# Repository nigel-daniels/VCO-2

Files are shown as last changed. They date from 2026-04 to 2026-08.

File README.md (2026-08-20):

# VCO 2

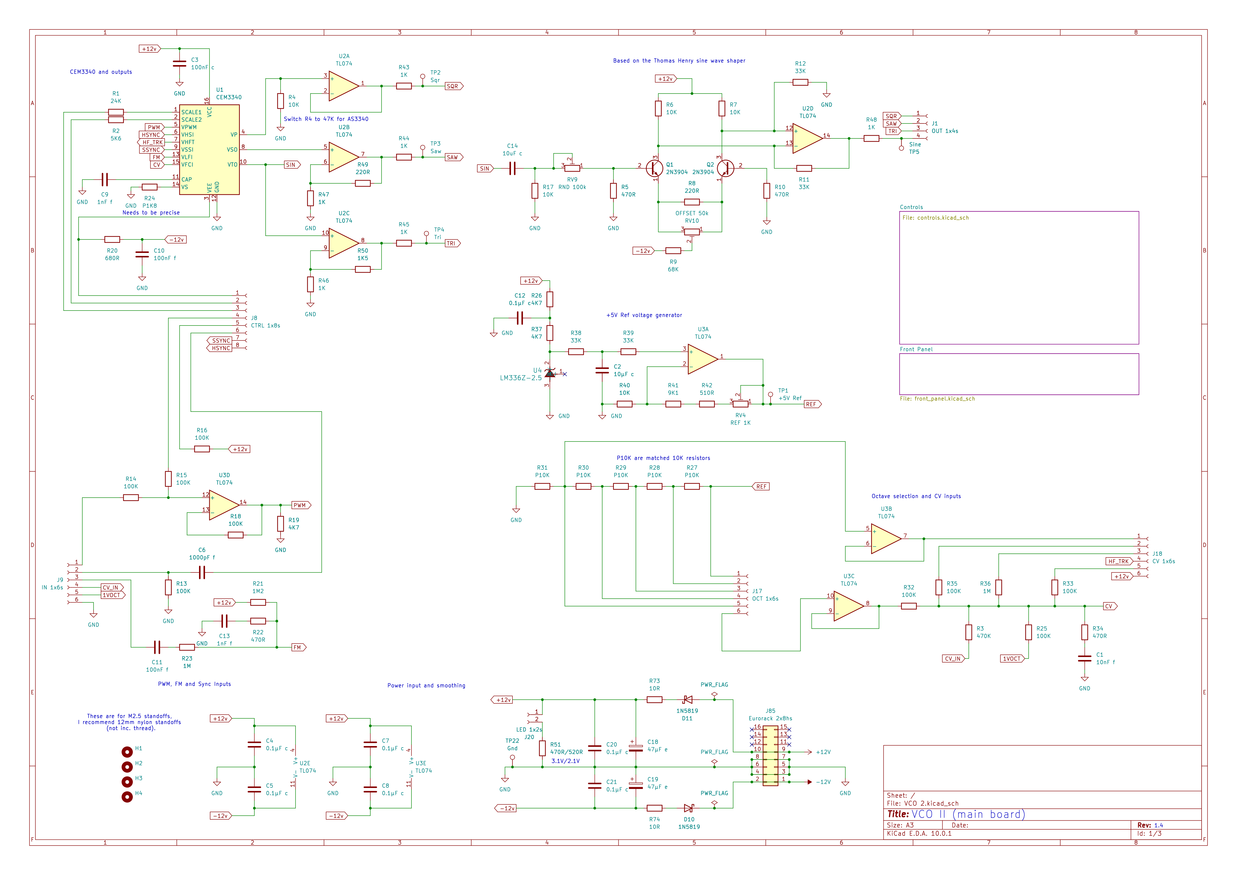
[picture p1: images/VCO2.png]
Main board schematic


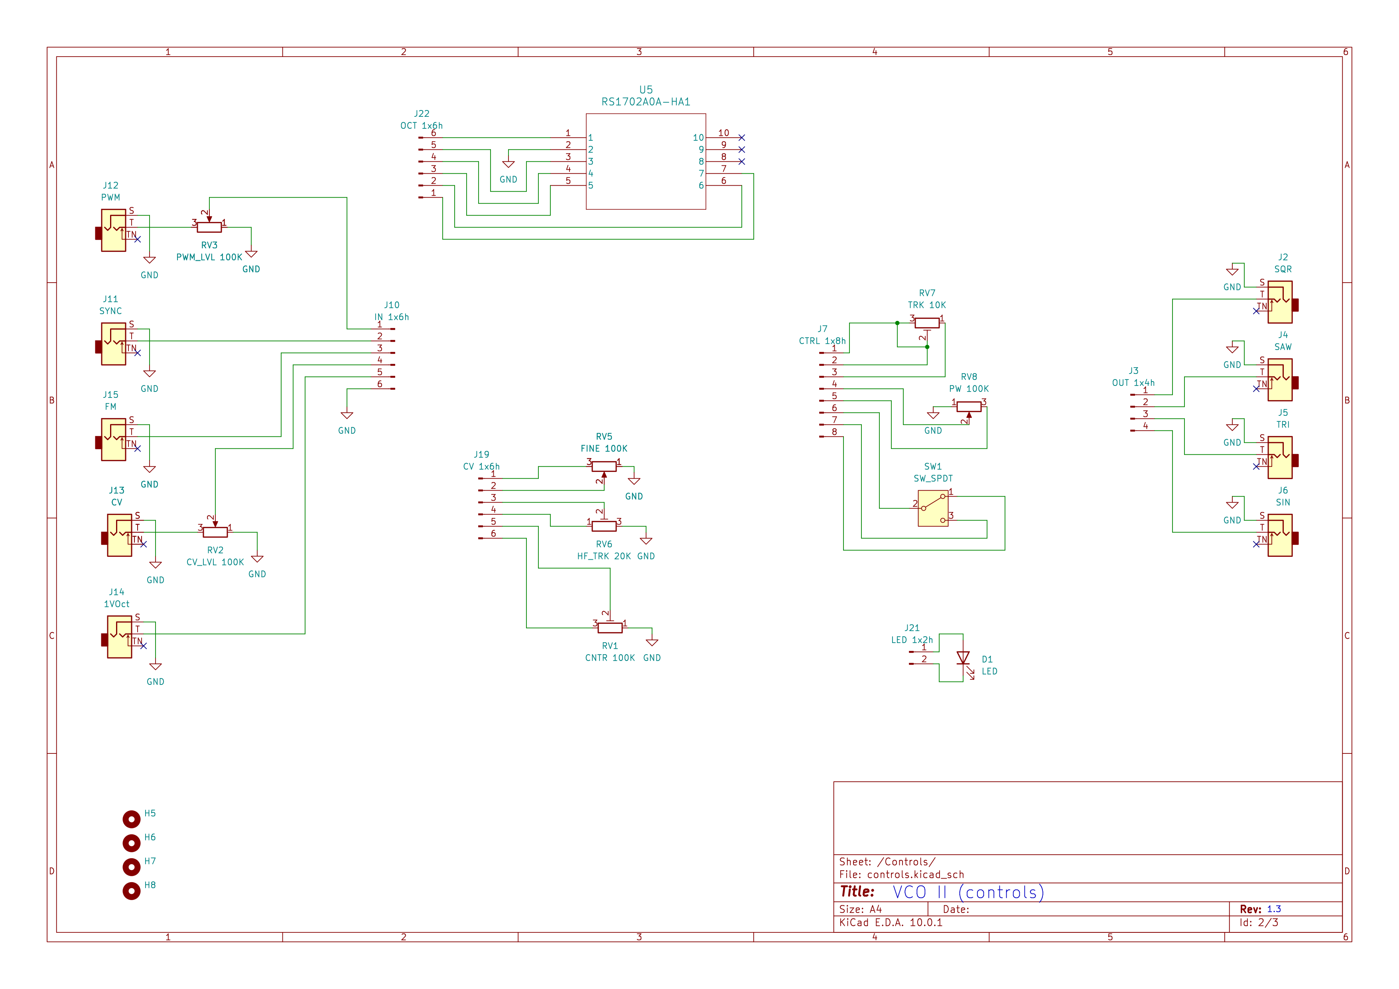
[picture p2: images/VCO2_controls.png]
Control board schematic


This VCO based on the work of  LMNC [performance VCO](https://www.lookmumnocomputer.com/1222-performance-vco). I've swapped out the built in tuner for a sine wave generator based on the Henry Thomas design. I also expanded the octave range by one and enabled hard/soft sync selection. Finally I've set the gain on the output Op-Amps so that everything is around 9-10V out. Why drop the tuner? Well, I'm unlikely to go performing and I was thinking I'll just build a single tuning module to take advantage of the control panel trim pots.

There are a couple of folders included, these contain footprints I used for the switches, import these as project specific items. There is also a JLCPCB folder for the fabrication files of the PCB, I used [JLCPCB](https://jlcpcb.com) for producing this complex board. The PCB design is my own.

I hope you find this useful, and a huge thanks to the LMNC site for some inspiration to do this version of a VCO, also to the lovely people at OnChip Systems (nee [Curtis Electromusic](https://www.curtiselectromusic.com)) who still manufacture and supply the CEM3340. I tracked them down here in San Jose to buy from the source ;)

## Calibration

### Set the reference voltage
Using the test points on the back of the module connect a multimeter in DC mode to GND (`TP22`) and `TP1` for the 5V reference. Use the trimpot next to  `TP1` to tune the voltage to read 5V.

### Shape the sine wave
Now connect an oscilloscope to the sine wave output and use the the other two trimpots to ensure the output sine wave has a good sinusoidal shape. The upper trimpot sets the roundness of the wave and the lower trimpot sets the offset.

### Tuning the module
On the front panel are three trimpots used to keep the module in tune. For this you'll need a tuner, I just use an app called `Tuner` on my phone. Also fire up the module where you plan to use it an leave it running for about half an hour so it settles to the ambient temperature of your location (this is especially important if you just moved the synth to a new location).
1. First use the `Course` trimpot to get the octave selector covering the sort of range you want.
2. Now use the `Track` trimpot to ensure that each selection on the octave selector is one octave apart from the adjacent options.
3. Once everything is one octave appart you can use the `Course` trimpot to adjust everything to be on a specific note. You may need to iterate these steps until it is all stable.

The `HF Trk` or High Frequency Track can be used in the same way as the `Track` trimpot but is for tuning to high frequencies.

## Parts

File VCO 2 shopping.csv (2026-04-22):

Qty | Value |  | Footprint
1 | 10nF f | 103 | Capacitor_THT:C_Rect_L7.2mm_W2.5mm_P5.00mm
3 | 10uF c | 106 | Capacitor_THT:C_Disc_D4.7mm_W2.5mm_P5.00mm
1 | 100nF c | 104 | Capacitor_THT:C_Disc_D4.7mm_W2.5mm_P5.00mm
7 | 0.1uF c | 104 | Capacitor_THT:C_Disc_D4.7mm_W2.5mm_P5.00mm
1 | 1000pF f | 102 | Capacitor_THT:C_Rect_L7.2mm_W2.5mm_P5.00mm
2 | 1nF f | 102 | Capacitor_THT:C_Rect_L7.2mm_W2.5mm_P5.00mm
2 | 100nF f | 104/100n | Capacitor_THT:C_Rect_L7.2mm_W2.5mm_P5.00mm
2 | 47uF e |  | Capacitor_THT:CP_Radial_D5.0mm_P2.50mm
1 | LED |  | LED_THT:LED_D3.0mm_FlatTop
2 | 1N5819 |  | Diode_THT:D_DO-41_SOD81_P10.16mm_Horizontal
1 | connector 1x4s |  | Connector_PinSocket_2.54mm:PinSocket_1x04_P2.54mm_Vertical
1 | connector 1x4h |  | Connector_PinHeader_2.54mm:PinHeader_1x04_P2.54mm_Vertical
1 | connector 1x8h |  | Connector_PinHeader_2.54mm:PinHeader_1x08_P2.54mm_Vertical
1 | connector 1x8s |  | Connector_PinSocket_2.54mm:PinSocket_1x08_P2.54mm_Vertical
3 | connector 1x6s |  | Connector_PinSocket_2.54mm:PinSocket_1x06_P2.54mm_Vertical
3 | connector 1x6h |  | Connector_PinHeader_2.54mm:PinHeader_1x06_P2.54mm_Vertical
9 | Thonkiconn |  | Connector_Audio:Jack_3.5mm_QingPu_WQP-PJ398SM_Vertical_CircularHoles
1 | connector 1x2s |  | Connector_PinSocket_2.54mm:PinSocket_1x02_P2.54mm_Vertical
1 | connector 1x2h |  | Connector_PinHeader_2.54mm:PinHeader_1x02_P2.54mm_Vertical
1 | Eurorack 2x8hs |  | Connector_PinHeader_2.54mm:PinHeader_2x08_P2.54mm_Vertical
2 | 2N3904 |  | Package_TO_SOT_THT:TO-92_Inline_Wide
1 | 24K |  | Resistor_THT:R_Axial_DIN0204_L3.6mm_D1.6mm_P7.62mm_Horizontal
1 | 5K6 |  | Resistor_THT:R_Axial_DIN0204_L3.6mm_D1.6mm_P2.54mm_Vertical
1 | 470K |  | Resistor_THT:R_Axial_DIN0204_L3.6mm_D1.6mm_P7.62mm_Horizontal
5 | 10K |  | Resistor_THT:R_Axial_DIN0204_L3.6mm_D1.6mm_P2.54mm_Vertical
4 | 470R |  | Resistor_THT:R_Axial_DIN0204_L3.6mm_D1.6mm_P2.54mm_Vertical
2 | 220R |  | Resistor_THT:R_Axial_DIN0204_L3.6mm_D1.6mm_P2.54mm_Vertical
1 | 68K |  | Resistor_THT:R_Axial_DIN0204_L3.6mm_D1.6mm_P2.54mm_Vertical
4 | 33K |  | Resistor_THT:R_Axial_DIN0204_L3.6mm_D1.6mm_P2.54mm_Vertical
9 | 100K |  | Resistor_THT:R_Axial_DIN0204_L3.6mm_D1.6mm_P2.54mm_Vertical
3 | 4K7 |  | Resistor_THT:R_Axial_DIN0204_L3.6mm_D1.6mm_P2.54mm_Vertical
1 | 680R |  | Resistor_THT:R_Axial_DIN0204_L3.6mm_D1.6mm_P2.54mm_Vertical
1 | 1M5 |  | Resistor_THT:R_Axial_DIN0204_L3.6mm_D1.6mm_P2.54mm_Vertical
2 | 1M |  | Resistor_THT:R_Axial_DIN0204_L3.6mm_D1.6mm_P7.62mm_Horizontal
1 | P 1K8 |  | Resistor_THT:R_Axial_DIN0204_L3.6mm_D1.6mm_P2.54mm_Vertical
5 | P 10K |  | Resistor_THT:R_Axial_DIN0204_L3.6mm_D1.6mm_P2.54mm_Vertical
1 | 9K1 |  | Resistor_THT:R_Axial_DIN0204_L3.6mm_D1.6mm_P2.54mm_Vertical
1 | 510R |  | Resistor_THT:R_Axial_DIN0204_L3.6mm_D1.6mm_P2.54mm_Vertical
6 | 1K |  | Resistor_THT:R_Axial_DIN0204_L3.6mm_D1.6mm_P2.54mm_Vertical
1 | 1K5 |  | Resistor_THT:R_Axial_DIN0204_L3.6mm_D1.6mm_P2.54mm_Vertical
1 | 470R/520R |  | Resistor_THT:R_Axial_DIN0204_L3.6mm_D1.6mm_P2.54mm_Vertical
2 | 10R |  | Resistor_THT:R_Axial_DIN0204_L3.6mm_D1.6mm_P2.54mm_Vertical
2 | Trim pot 100K |  | Potentiometer_THT:Potentiometer_Bourns_3296W_Vertical
4 | Pot 100K |  | Potentiometer_THT:Potentiometer_Alps_RK09L_Single_Vertical
1 | Trim pot 1K |  | Potentiometer_THT:Potentiometer_Bourns_3296W_Vertical
1 | Trim pot 20K |  | Potentiometer_THT:Potentiometer_Bourns_3296W_Vertical
1 | Trim pot 10K |  | Potentiometer_THT:Potentiometer_Bourns_3296W_Vertical
1 | Trim pot 50k |  | Potentiometer_THT:Potentiometer_Bourns_3296W_Vertical
1 | SW_SPDT |  | sub-miniture-SPDT:Sub-miniture SPDT
6 | Test point |  | TestPoint:TestPoint_Loop_D2.50mm_Drill1.0mm
1 | CEM3340 |  | Package_DIP:DIP-16_W7.62mm
2 | TL074 |  | Package_DIP:DIP-14_W7.62mm
1 | LM336Z-2.5 |  | Voltage Ref Diode:Z03A
1 | RS1702A0A-HA1 |  | Rotary 6-Way SW:rotary-6-way-sw

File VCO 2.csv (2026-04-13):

Reference | Qty | Value | Footprint
C1 | 1 | 10nF f | Capacitor_THT:C_Rect_L7.2mm_W2.5mm_P5.00mm
C2 | 2 | 10_F c | Capacitor_THT:C_Disc_D4.7mm_W2.5mm_P5.00mm
C3 | 1 | 100nF c | Capacitor_THT:C_Disc_D4.7mm_W2.5mm_P5.00mm
C4,C5,C7,C8,C12,C20,C21 | 7 | 0.1_F c | Capacitor_THT:C_Disc_D4.7mm_W2.5mm_P5.00mm
C6 | 1 | 1000pF f | Capacitor_THT:C_Rect_L7.2mm_W2.5mm_P5.00mm
C9,C13 | 2 | 1nF f | Capacitor_THT:C_Rect_L7.2mm_W2.5mm_P5.00mm
C10,C11 | 2 | 100nF f | Capacitor_THT:C_Rect_L7.2mm_W2.5mm_P5.00mm
C14 | 1 | 10uF c | Capacitor_THT:C_Disc_D4.7mm_W2.5mm_P5.00mm
C18,C19 | 2 | 47_F e | Capacitor_THT:CP_Radial_D5.0mm_P2.50mm
D1 | 1 | LED | LED_THT:LED_D3.0mm_FlatTop
D10,D11 | 2 | 1N5819 | Diode_THT:D_DO-41_SOD81_P10.16mm_Horizontal
J1 | 1 | OUT 1x4s | Connector_PinSocket_2.54mm:PinSocket_1x04_P2.54mm_Vertical
J2 | 1 | SQR | Connector_Audio:Jack_3.5mm_QingPu_WQP-PJ398SM_Vertical_CircularHoles
J3 | 1 | OUT 1x4h | Connector_PinHeader_2.54mm:PinHeader_1x04_P2.54mm_Vertical
J4 | 1 | SAW | Connector_Audio:Jack_3.5mm_QingPu_WQP-PJ398SM_Vertical_CircularHoles
J5 | 1 | TRI | Connector_Audio:Jack_3.5mm_QingPu_WQP-PJ398SM_Vertical_CircularHoles
J6 | 1 | SIN | Connector_Audio:Jack_3.5mm_QingPu_WQP-PJ398SM_Vertical_CircularHoles
J7 | 1 | CTRL 1x8h | Connector_PinHeader_2.54mm:PinHeader_1x08_P2.54mm_Vertical
J8 | 1 | CTRL 1x8s | Connector_PinSocket_2.54mm:PinSocket_1x08_P2.54mm_Vertical
J9 | 1 | IN 1x6s | Connector_PinSocket_2.54mm:PinSocket_1x06_P2.54mm_Vertical
J10 | 1 | IN 1x6h | Connector_PinHeader_2.54mm:PinHeader_1x06_P2.54mm_Vertical
J11 | 1 | SYNC | Connector_Audio:Jack_3.5mm_QingPu_WQP-PJ398SM_Vertical_CircularHoles
J12 | 1 | PWM | Connector_Audio:Jack_3.5mm_QingPu_WQP-PJ398SM_Vertical_CircularHoles
J13 | 1 | CV | Connector_Audio:Jack_3.5mm_QingPu_WQP-PJ398SM_Vertical_CircularHoles
J14 | 1 | 1VOct | Connector_Audio:Jack_3.5mm_QingPu_WQP-PJ398SM_Vertical_CircularHoles
J15 | 1 | FM | Connector_Audio:Jack_3.5mm_QingPu_WQP-PJ398SM_Vertical_CircularHoles
J17 | 1 | OCT 1x6s | Connector_PinSocket_2.54mm:PinSocket_1x06_P2.54mm_Vertical
J18 | 1 | CV 1x6s | Connector_PinSocket_2.54mm:PinSocket_1x06_P2.54mm_Vertical
J19 | 1 | CV 1x6h | Connector_PinHeader_2.54mm:PinHeader_1x06_P2.54mm_Vertical
J20 | 1 | LED 1x2s | Connector_PinSocket_2.54mm:PinSocket_1x02_P2.54mm_Vertical
J21 | 1 | LED 1x2h | Connector_PinHeader_2.54mm:PinHeader_1x02_P2.54mm_Vertical
J22 | 1 | OCT 1x6h | Connector_PinHeader_2.54mm:PinHeader_1x06_P2.54mm_Vertical
J85 | 1 | Eurorack 2x8hs | Connector_PinHeader_2.54mm:PinHeader_2x08_P2.54mm_Vertical
Q1,Q2 | 2 | 2N3904 | Package_TO_SOT_THT:TO-92_Inline_Wide
R1 | 1 | 24K | Resistor_THT:R_Axial_DIN0204_L3.6mm_D1.6mm_P7.62mm_Horizontal
R2 | 1 | 5K6 | Resistor_THT:R_Axial_DIN0204_L3.6mm_D1.6mm_P2.54mm_Vertical
R3 | 1 | 470K | Resistor_THT:R_Axial_DIN0204_L3.6mm_D1.6mm_P7.62mm_Horizontal
R4,R7,R17,R40 | 4 | 10K | Resistor_THT:R_Axial_DIN0204_L3.6mm_D1.6mm_P2.54mm_Vertical
R5,R10,R34 | 3 | 470R | Resistor_THT:R_Axial_DIN0204_L3.6mm_D1.6mm_P2.54mm_Vertical
R6 | 1 | 10K | Resistor_THT:R_Axial_DIN0204_L3.6mm_D1.6mm_P7.62mm_Horizontal
R8 | 1 | 220R | Resistor_THT:R_Axial_DIN0204_L3.6mm_D1.6mm_P2.54mm_Vertical
R9 | 1 | 68K | Resistor_THT:R_Axial_DIN0204_L3.6mm_D1.6mm_P2.54mm_Vertical
R11,R12,R38,R39 | 4 | 33K | Resistor_THT:R_Axial_DIN0204_L3.6mm_D1.6mm_P2.54mm_Vertical
R13,R14,R15,R16,R18,R33,R35 | 7 | 100K | Resistor_THT:R_Axial_DIN0204_L3.6mm_D1.6mm_P2.54mm_Vertical
R19,R26,R37 | 3 | 4K7 | Resistor_THT:R_Axial_DIN0204_L3.6mm_D1.6mm_P2.54mm_Vertical
R20 | 1 | 680R | Resistor_THT:R_Axial_DIN0204_L3.6mm_D1.6mm_P2.54mm_Vertical
R21 | 1 | 1M2 | Resistor_THT:R_Axial_DIN0204_L3.6mm_D1.6mm_P2.54mm_Vertical
R22 | 1 | 470R | Resistor_THT:R_Axial_DIN0204_L3.6mm_D1.6mm_P7.62mm_Horizontal
R23 | 1 | 1M | Resistor_THT:R_Axial_DIN0204_L3.6mm_D1.6mm_P7.62mm_Horizontal
R24 | 1 | P 1K8 | Resistor_THT:R_Axial_DIN0204_L3.6mm_D1.6mm_P2.54mm_Vertical
R25,R32 | 2 | 100K | Resistor_THT:R_Axial_DIN0204_L3.6mm_D1.6mm_P7.62mm_Horizontal
R27,R28,R29,R30,R31 | 5 | P 10K | Resistor_THT:R_Axial_DIN0204_L3.6mm_D1.6mm_P2.54mm_Vertical
R36 | 1 | 1M | Resistor_THT:R_Axial_DIN0204_L3.6mm_D1.6mm_P2.54mm_Vertical
R41 | 1 | 9K1 | Resistor_THT:R_Axial_DIN0204_L3.6mm_D1.6mm_P2.54mm_Vertical
R42 | 1 | 510R | Resistor_THT:R_Axial_DIN0204_L3.6mm_D1.6mm_P2.54mm_Vertical
R43,R44,R45,R46,R47 | 5 | 1K | Resistor_THT:R_Axial_DIN0204_L3.6mm_D1.6mm_P2.54mm_Vertical
R48 | 1 | 1K | Resistor_THT:R_Axial_DIN0204_L3.6mm_D1.6mm_P7.62mm_Horizontal
R49 | 1 | 220R | Resistor_THT:R_Axial_DIN0204_L3.6mm_D1.6mm_P2.54mm_Vertical
R50 | 1 | 1K5 | Resistor_THT:R_Axial_DIN0204_L3.6mm_D1.6mm_P2.54mm_Vertical
R51 | 1 | 470R/520R | Resistor_THT:R_Axial_DIN0204_L3.6mm_D1.6mm_P2.54mm_Vertical
R73,R74 | 2 | 10R | Resistor_THT:R_Axial_DIN0204_L3.6mm_D1.6mm_P2.54mm_Vertical
RV1 | 1 | CNTR 100K | Potentiometer_THT:Potentiometer_Bourns_3296W_Vertical
RV2 | 1 | CV_LVL 100K | Potentiometer_THT:Potentiometer_Alps_RK09L_Single_Vertical
RV3 | 1 | PWM_LVL 100K | Potentiometer_THT:Potentiometer_Alps_RK09L_Single_Vertical
RV4 | 1 | REF 1K | Potentiometer_THT:Potentiometer_Bourns_3296W_Vertical
RV5 | 1 | FINE 100K | Potentiometer_THT:Potentiometer_Alps_RK09L_Single_Vertical
RV6 | 1 | HF_TRK 20K | Potentiometer_THT:Potentiometer_Bourns_3296W_Vertical
RV7 | 1 | TRK 10K | Potentiometer_THT:Potentiometer_Bourns_3296W_Vertical
RV8 | 1 | PW 100K | Potentiometer_THT:Potentiometer_Alps_RK09L_Single_Vertical
RV9 | 1 | RND 100k | Potentiometer_THT:Potentiometer_Bourns_3296W_Vertical
RV10 | 1 | OFFSET 50k | Potentiometer_THT:Potentiometer_Bourns_3296W_Vertical
SW1 | 1 | SW_SPDT | sub-miniture-SPDT:Sub-miniture SPDT
TP1 | 1 | +5V Ref | TestPoint:TestPoint_Loop_D2.50mm_Drill1.0mm
TP2 | 1 | Sqr | TestPoint:TestPoint_Loop_D2.50mm_Drill1.0mm
TP3 | 1 | Saw | TestPoint:TestPoint_Loop_D2.50mm_Drill1.0mm
TP4 | 1 | Tri | TestPoint:TestPoint_Loop_D2.50mm_Drill1.0mm
TP5 | 1 | Sine | TestPoint:TestPoint_Loop_D2.50mm_Drill1.0mm
TP22 | 1 | Gnd | TestPoint:TestPoint_Loop_D2.50mm_Drill1.0mm
U1 | 1 | CEM3340 | Package_DIP:DIP-16_W7.62mm
U2,U3 | 2 | TL074 | Package_DIP:DIP-14_W7.62mm
U4 | 1 | LM336Z-2.5 | Voltage Ref Diode:Z03A
U5 | 1 | RS1702A0A-HA1 | Rotary 6-Way SW:rotary-6-way-sw

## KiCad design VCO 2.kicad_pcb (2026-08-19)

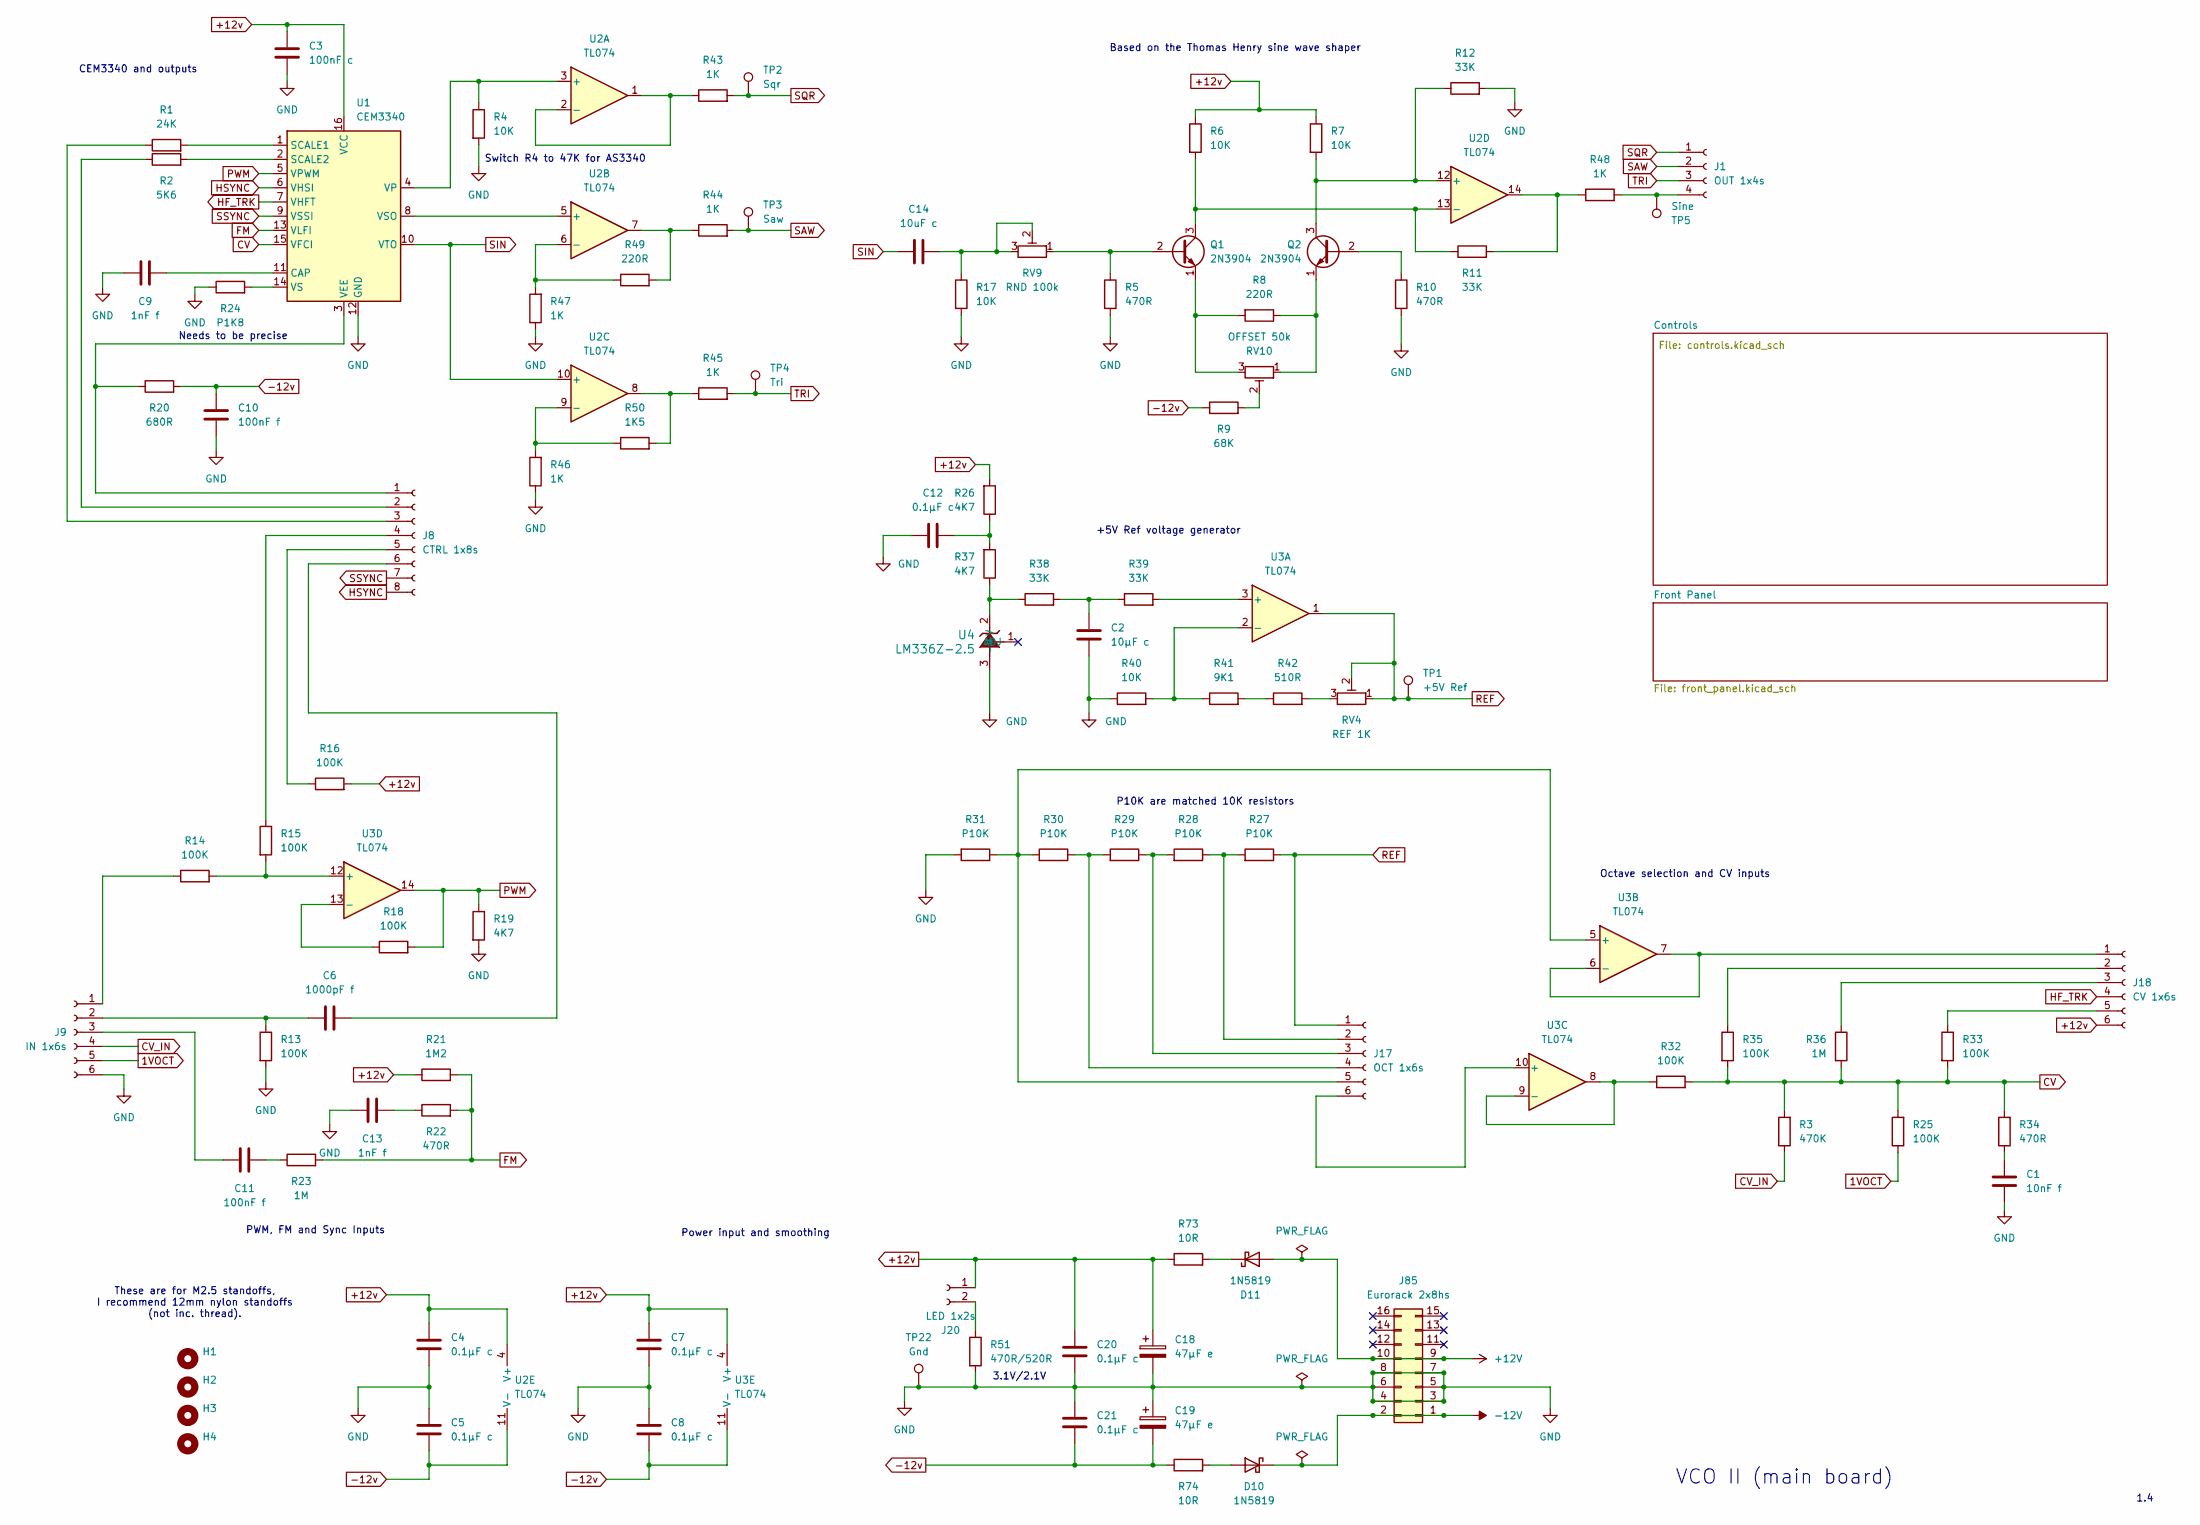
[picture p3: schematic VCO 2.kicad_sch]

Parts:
C1: 10nF f; C_Rect_L7.2mm_W2.5mm_P5.00mm
C2: 10μF c; C_Disc_D4.7mm_W2.5mm_P5.00mm
C3: 100nF c; C_Disc_D4.7mm_W2.5mm_P5.00mm
C4, C5, C7, C8, C12, C20, C21: 0.1μF c; C_Disc_D4.7mm_W2.5mm_P5.00mm
C6: 1000pF f; C_Rect_L7.2mm_W2.5mm_P5.00mm
C9, C13: 1nF f; C_Rect_L7.2mm_W2.5mm_P5.00mm
C10, C11: 100nF f; C_Rect_L7.2mm_W2.5mm_P5.00mm
C14: 10uF c; C_Disc_D4.7mm_W2.5mm_P5.00mm
C18, C19: 47μF e; CP_Radial_D5.0mm_P2.50mm
D10, D11: 1N5819; D_DO-41_SOD81_P10.16mm_Horizontal
H1, H2, H3, H4: MountingHole_2.7mm_M2.5
J1: OUT 1x4s; PinSocket_1x04_P2.54mm_Vertical
J8: CTRL 1x8s; PinSocket_1x08_P2.54mm_Vertical
J9: IN 1x6s; PinSocket_1x06_P2.54mm_Vertical
J17: OCT 1x6s; PinSocket_1x06_P2.54mm_Vertical
J18: CV 1x6s; PinSocket_1x06_P2.54mm_Vertical
J20: LED 1x2s; PinSocket_1x02_P2.54mm_Vertical
J85: Eurorack 2x8hs; PinHeader_2x08_P2.54mm_Vertical
Q1, Q2: 2N3904; TO-92_Inline_Wide
R1: 24K; R_Axial_DIN0204_L3.6mm_D1.6mm_P7.62mm_Horizontal
R2: 5K6; R_Axial_DIN0204_L3.6mm_D1.6mm_P2.54mm_Vertical
R3: 470K; R_Axial_DIN0204_L3.6mm_D1.6mm_P7.62mm_Horizontal
R4, R7, R17, R40: 10K; R_Axial_DIN0204_L3.6mm_D1.6mm_P2.54mm_Vertical
R5, R10, R34: 470R; R_Axial_DIN0204_L3.6mm_D1.6mm_P2.54mm_Vertical
R6: 10K; R_Axial_DIN0204_L3.6mm_D1.6mm_P7.62mm_Horizontal
R8, R49: 220R; R_Axial_DIN0204_L3.6mm_D1.6mm_P2.54mm_Vertical
R9: 68K; R_Axial_DIN0204_L3.6mm_D1.6mm_P2.54mm_Vertical
R11, R12, R38, R39: 33K; R_Axial_DIN0204_L3.6mm_D1.6mm_P2.54mm_Vertical
R13, R14, R15, R16, R18, R33, R35: 100K; R_Axial_DIN0204_L3.6mm_D1.6mm_P2.54mm_Vertical
R19, R26, R37: 4K7; R_Axial_DIN0204_L3.6mm_D1.6mm_P2.54mm_Vertical
R20: 680R; R_Axial_DIN0204_L3.6mm_D1.6mm_P2.54mm_Vertical
R21: 1M2; R_Axial_DIN0204_L3.6mm_D1.6mm_P2.54mm_Vertical
R22: 470R; R_Axial_DIN0204_L3.6mm_D1.6mm_P7.62mm_Horizontal
R23: 1M; R_Axial_DIN0204_L3.6mm_D1.6mm_P7.62mm_Horizontal
R24: P1K8; R_Axial_DIN0204_L3.6mm_D1.6mm_P2.54mm_Vertical
R25, R32: 100K; R_Axial_DIN0204_L3.6mm_D1.6mm_P7.62mm_Horizontal
R27, R28, R29, R30, R31: P10K; R_Axial_DIN0204_L3.6mm_D1.6mm_P2.54mm_Vertical
R36: 1M; R_Axial_DIN0204_L3.6mm_D1.6mm_P2.54mm_Vertical
R41: 9K1; R_Axial_DIN0204_L3.6mm_D1.6mm_P2.54mm_Vertical
R42: 510R; R_Axial_DIN0204_L3.6mm_D1.6mm_P2.54mm_Vertical
R43, R44, R45, R46, R47: 1K; R_Axial_DIN0204_L3.6mm_D1.6mm_P2.54mm_Vertical
R48: 1K; R_Axial_DIN0204_L3.6mm_D1.6mm_P7.62mm_Horizontal
R50: 1K5; R_Axial_DIN0204_L3.6mm_D1.6mm_P2.54mm_Vertical
R51: 470R/520R; R_Axial_DIN0204_L3.6mm_D1.6mm_P2.54mm_Vertical
R73, R74: 10R; R_Axial_DIN0204_L3.6mm_D1.6mm_P2.54mm_Vertical
RV4: REF 1K; Potentiometer_Bourns_3296W_Vertical
RV9: RND 100k; Potentiometer_Bourns_3296W_Vertical
RV10: OFFSET 50k; Potentiometer_Bourns_3296W_Vertical
TP1: +5V Ref; TestPoint_Loop_D2.50mm_Drill1.0mm
TP2: Sqr; TestPoint_Loop_D2.50mm_Drill1.0mm
TP3: Saw; TestPoint_Loop_D2.50mm_Drill1.0mm
TP4: Tri; TestPoint_Loop_D2.50mm_Drill1.0mm
TP5: Sine; TestPoint_Loop_D2.50mm_Drill1.0mm
TP22: Gnd; TestPoint_Loop_D2.50mm_Drill1.0mm
U1: CEM3340; DIP-16_W7.62mm
U2, U3: TL074; DIP-14_W7.62mm
U4: LM336Z-2.5; Z03A

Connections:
1VOCT: J9.5, R25.1
+12V: D11.2 (A), J85.9, J85.10
+12v: C3.1, C4.1, C7.1, C18.1, C20.1, J18.6, J20.1, R6.1, R7.1, R16.2, R21.1, R26.2, R73.1, U1.16 (VCC), U2.4 (V+), U3.4 (V+)
-12V: D10.1 (K), J85.1, J85.2
-12v: C5.2, C8.2, C10.2, C19.2, C21.2, R9.1, R20.2, R74.1, U2.11 (V-), U3.11 (V-)
CV: R3.2, R25.2, R32.2, R33.2, R34.2, R35.2, R36.2, U1.15 (VFCI)
CV_IN: J9.4, R3.1
FM: R21.2, R22.2, R23.2, U1.13 (VLFI)
GND: C1.2, C2.2, C3.2, C4.2, C5.1, C7.2, C8.1, C9.2, C10.1, C12.2, C13.1, C18.2, C19.1, C20.2, C21.1, J9.6, J85.3, J85.4, J85.5, J85.6, J85.7, J85.8, R4.2, R5.2, R10.2, R12.2, R13.2, R17.2, R19.2, R24.1, R31.2, R40.1, R46.1, R47.1, R51.2, TP22.1 (1_1), U1.12 (GND), U4.3 (-V); also elsewhere on the board
HF_TRK: J18.4, U1.7 (VHFT)
HSYNC: J8.8, U1.6 (VHSI)
unnamed: C1.1, R34.1
unnamed: C2.1, R38.2, R39.1
unnamed: C11.2, R23.1
unnamed: C12.1, R26.1, R37.2
unnamed: C13.2, R22.1
unnamed: C14.1, R17.1, RV9.2, RV9.3
unnamed: D10.2 (A), R74.2
unnamed: D11.1 (K), R73.2
unnamed: J1.4, R48.2, TP5.1 (1_1)
unnamed: J8.1, R20.1, U1.3 (VEE)
unnamed: J8.2, R2.1
unnamed: J8.3, R1.1
unnamed: J8.4, R15.1
unnamed: J8.5, R16.1
unnamed: C6.1, J8.6
unnamed: J9.1, R14.1
unnamed: C6.2, J9.2, R13.1
unnamed: C11.1, J9.3
unnamed: J17.2, R27.2, R28.1
unnamed: J17.3, R28.2, R29.1
unnamed: J17.4, R29.2, R30.1
unnamed: J17.5, R30.2, R31.1, U3.5 (+)
unnamed: J17.6, U3.10 (+)
unnamed: J18.1, U3.6 (-), U3.7
unnamed: J18.2, R35.1
unnamed: J18.3, R36.1
unnamed: J18.5, R33.1
unnamed: J20.2, R51.1
unnamed: Q1.2 (B), R5.1, RV9.1
unnamed: Q1.3 (C), R6.2, R11.1, U2.13 (-)
unnamed: Q1.1 (E), R8.2, RV10.3
unnamed: Q2.2 (B), R10.1
unnamed: Q2.3 (C), R7.2, R12.1, U2.12 (+)
unnamed: Q2.1 (E), R8.1, RV10.1
unnamed: R9.2, RV10.2
unnamed: R11.2, R48.1, U2.14
unnamed: R41.2, R42.1
unnamed: R42.2, RV4.3
unnamed: R44.1, R49.2, U2.7
unnamed: R45.1, R50.2, U2.8
unnamed: C9.1, U1.11 (CAP)
unnamed: R1.2, U1.1 (SCALE1)
unnamed: R2.2, U1.2 (SCALE2)
unnamed: R4.1, U1.4 (VP), U2.3 (+)
unnamed: R24.2, U1.14 (VS)
unnamed: U1.8 (VSO), U2.5 (+)
unnamed: R43.1, U2.1, U2.2 (-)
unnamed: R47.2, R49.1, U2.6 (-)
unnamed: R46.2, R50.1, U2.9 (-)
unnamed: R39.2, U3.3 (+)
unnamed: R40.2, R41.1, U3.2 (-)
unnamed: R32.1, U3.8, U3.9 (-)
unnamed: R14.2, R15.2, U3.12 (+)
unnamed: R18.1, U3.13 (-)
unnamed: R37.1, R38.1, U4.2 (+V)
PWM: R18.2, R19.1, U1.5 (VPWM), U3.14
REF: J17.1, R27.1, RV4.1, RV4.2, TP1.1 (1_1), U3.1
SAW: J1.2, R44.2, TP3.1 (1_1)
SIN: C14.2, U1.10 (VTO), U2.10 (+)
SQR: J1.1, R43.2, TP2.1 (1_1)
SSYNC: J8.7, U1.9 (VSSI)
TRI: J1.3, R45.2, TP4.1 (1_1)

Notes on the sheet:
3.1V/2.1V
CEM3340 and outputs
Needs to be precise
Switch R4 to 47K for AS3340
+5V Ref voltage generator
These are for M2.5 standoffs, I recommend 12mm nylon standoffs (not inc. thread).
P10K are matched 10K resistors
Based on the Thomas Henry sine wave shaper
1.4
PWM, FM and Sync Inputs
Power input and smoothing
VCO II (main board)
Octave selection and CV inputs

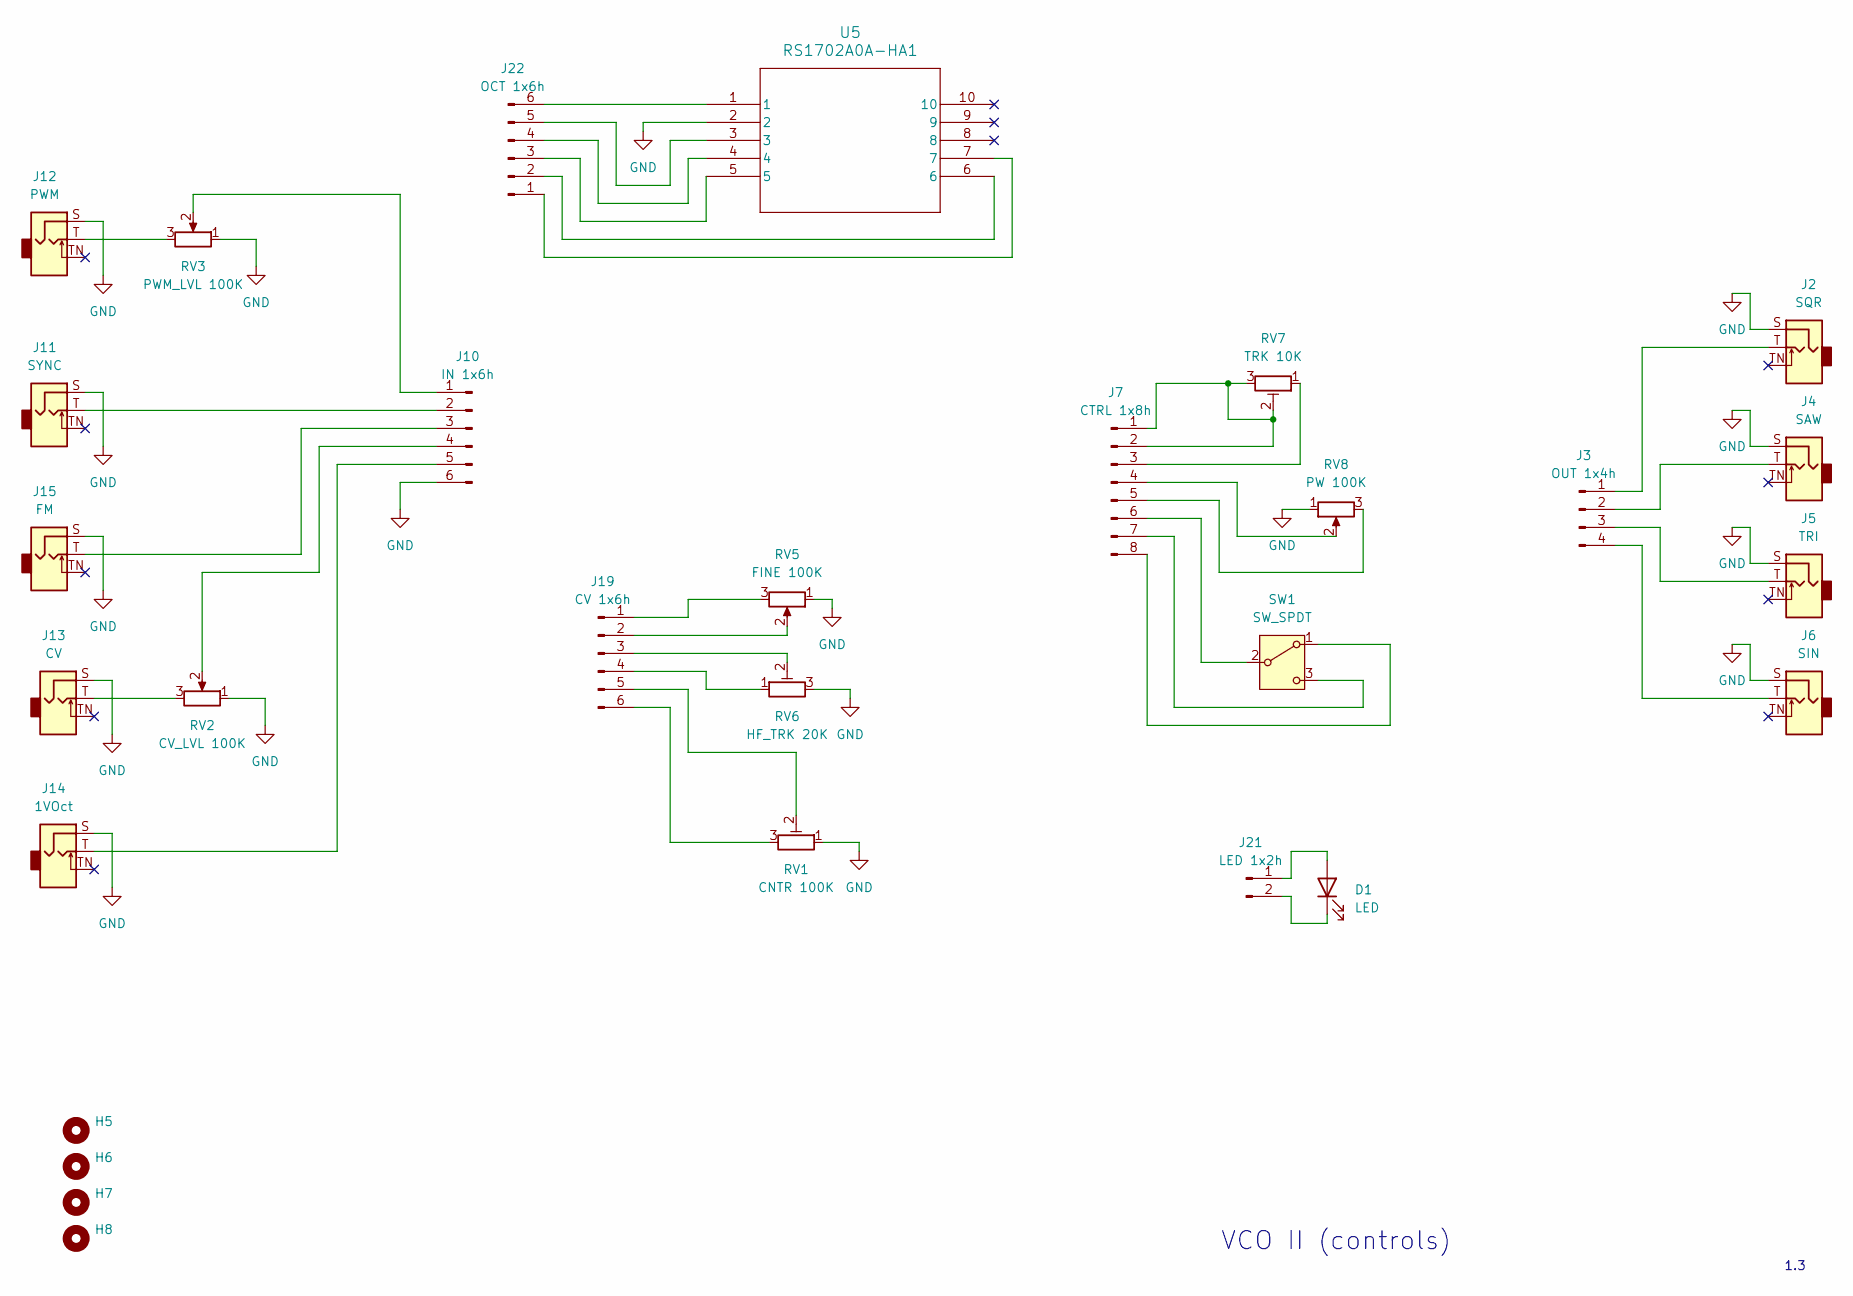
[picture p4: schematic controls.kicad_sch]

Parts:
D1: LED; LED_D3.0mm_FlatTop
H5, H6, H7, H8: MountingHole_2.7mm_M2.5
J2: SQR; Jack_3.5mm_QingPu_WQP-PJ398SM_Vertical_CircularHoles
J3: OUT 1x4h; PinHeader_1x04_P2.54mm_Vertical
J4: SAW; Jack_3.5mm_QingPu_WQP-PJ398SM_Vertical_CircularHoles
J5: TRI; Jack_3.5mm_QingPu_WQP-PJ398SM_Vertical_CircularHoles
J6: SIN; Jack_3.5mm_QingPu_WQP-PJ398SM_Vertical_CircularHoles
J7: CTRL 1x8h; PinHeader_1x08_P2.54mm_Vertical
J10: IN 1x6h; PinHeader_1x06_P2.54mm_Vertical
J11: SYNC; Jack_3.5mm_QingPu_WQP-PJ398SM_Vertical_CircularHoles
J12: PWM; Jack_3.5mm_QingPu_WQP-PJ398SM_Vertical_CircularHoles
J13: CV; Jack_3.5mm_QingPu_WQP-PJ398SM_Vertical_CircularHoles
J14: 1VOct; Jack_3.5mm_QingPu_WQP-PJ398SM_Vertical_CircularHoles
J15: FM; Jack_3.5mm_QingPu_WQP-PJ398SM_Vertical_CircularHoles
J19: CV 1x6h; PinHeader_1x06_P2.54mm_Vertical
J21: LED 1x2h; PinHeader_1x02_P2.54mm_Vertical
J22: OCT 1x6h; PinHeader_1x06_P2.54mm_Vertical
RV1: CNTR 100K; Potentiometer_Bourns_3296W_Vertical
RV2: CV_LVL 100K; Potentiometer_Alps_RK09L_Single_Vertical
RV3: PWM_LVL 100K; Potentiometer_Alps_RK09L_Single_Vertical
RV5: FINE 100K; Potentiometer_Alps_RK09L_Single_Vertical
RV6: HF_TRK 20K; Potentiometer_Bourns_3296W_Vertical
RV7: TRK 10K; Potentiometer_Bourns_3296W_Vertical
RV8: PW 100K; Potentiometer_Alps_RK09L_Single_Vertical
SW1: SW_SPDT; Sub-miniture SPDT
U5: RS1702A0A-HA1; rotary-6-way-sw

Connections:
GND: J2.S, J4.S, J5.S, J6.S, J10.6, J11.S, J12.S, J13.S, J14.S, J15.S, RV1.1, RV2.1, RV3.1, RV5.1, RV6.3, RV8.1, U5.2; also elsewhere on the board
unnamed: D1.2 (A), J21.1
unnamed: D1.1 (K), J21.2
unnamed: J2.T, J3.1
unnamed: J3.2, J4.T
unnamed: J3.3, J5.T
unnamed: J3.4, J6.T
unnamed: J7.1, J7.2, RV7.2, RV7.3
unnamed: J7.3, RV7.1
unnamed: J7.4, RV8.2
unnamed: J7.5, RV8.3
unnamed: J7.6, SW1.2 (B)
unnamed: J7.7, SW1.3 (C)
unnamed: J7.8, SW1.1 (A)
unnamed: J10.1, RV3.2
unnamed: J10.2, J11.T
unnamed: J10.3, J15.T
unnamed: J10.4, RV2.2
unnamed: J10.5, J14.T
unnamed: J12.T, RV3.3
unnamed: J13.T, RV2.3
unnamed: J19.1, RV5.3
unnamed: J19.2, RV5.2
unnamed: J19.3, RV6.2
unnamed: J19.4, RV6.1
unnamed: J19.5, RV1.2
unnamed: J19.6, RV1.3
unnamed: J22.1, U5.7
unnamed: J22.2, U5.6
unnamed: J22.3, U5.5
unnamed: J22.4, U5.4
unnamed: J22.5, U5.3
unnamed: J22.6, U5.1

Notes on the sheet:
VCO II (controls)
1.3

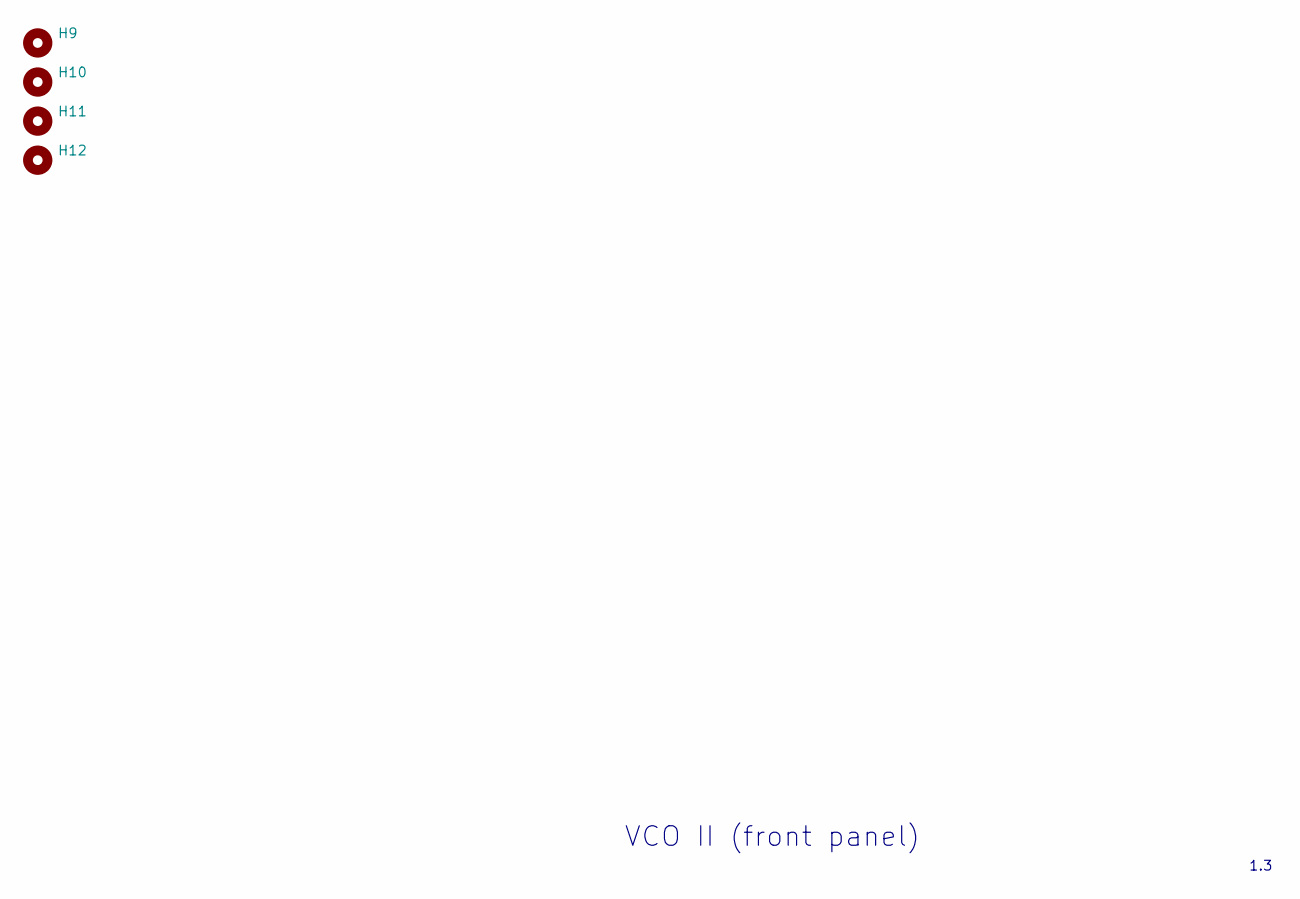
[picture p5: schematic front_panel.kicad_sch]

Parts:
H9, H10, H11, H12: MountingHole_3.2mm_M3

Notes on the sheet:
VCO II (front panel)
1.3

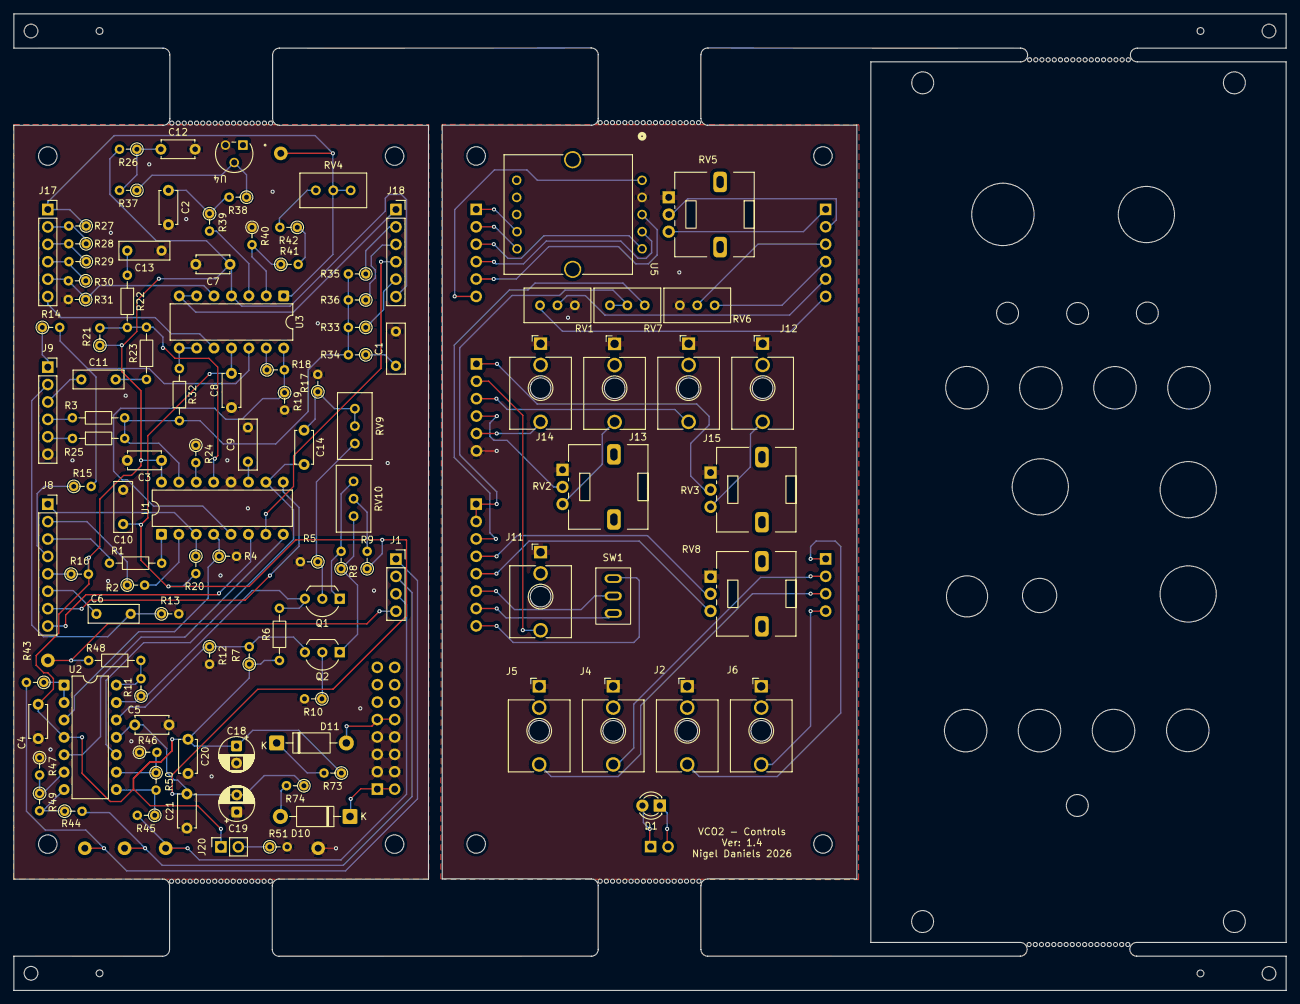
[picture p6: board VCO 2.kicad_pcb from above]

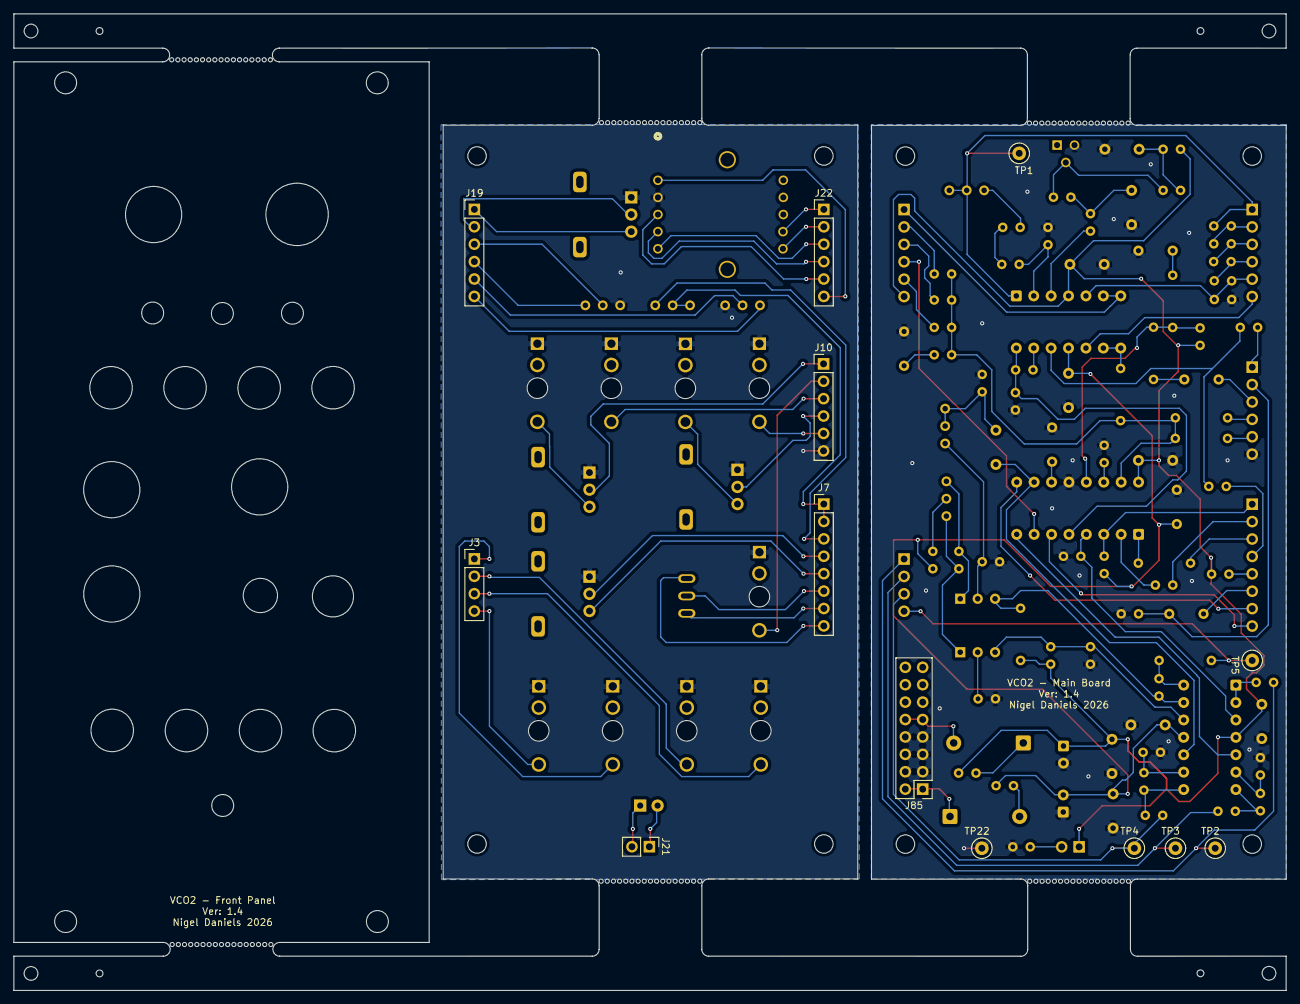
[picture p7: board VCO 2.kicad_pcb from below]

Board: 2 copper layers, 185.7 x 142.5 mm, 132 parts (13 on the bottom side), 105 nets.

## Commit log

2026-03-01 Added +5v ref supply
    [VCO 2.kicad_sch, untitled.kicad_sch]
2026-03-05 +5V ref update
    [VCO 2.kicad_sch, untitled.kicad_sch]
2026-03-08 Corrected output jack sockets
    [VCO 2.kicad_sch, untitled.kicad_sch]
2026-03-08 Updated ref design
    [VCO 2.kicad_sch]
2026-03-11 Updated simulator and corrected trk pot
    [untitled.kicad_sch]
2026-03-12 Added FM and PWM falstad models
2026-03-12 Updated FM PWM model
2026-03-24 Updates to jacks
    [VCO 2.kicad_sch, untitled.kicad_sch]
2026-03-27 Fixed FM sweep
    [VCO 2.kicad_sch, untitled.kicad_sch]
2026-03-27 Added decoupling C and R to prevent MacArches
    [VCO 2.kicad_sch]
2026-03-27 Added gain and 1k protection to output and LED, rerouted SIN feed.
    [VCO 2.kicad_sch]
2026-03-27 Added images to read me
    [untitled.kicad_sch]
2026-03-27 Moved LED to control board.
    [VCO 2.kicad_sch, untitled.kicad_sch]
2026-03-28 Update README.md
    Pulled PCB remark from old project
2026-03-28 Updated TP names
    [VCO 2.kicad_sch]
2026-03-31 Added fp and moved controls
    [VCO 2.kicad_pcb, VCO 2.kicad_sch, controls.kicad_sch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]
2026-04-02 Designed PCB and generated JLCPCB files
    [VCO 2-B_Cu.gbl, VCO 2-B_Mask.gbs, VCO 2-B_Paste.gbp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]
2026-04-02 Panelized design using tab and mouse bites
    [VCO 2-B_Cu.gbl, VCO 2-B_Mask.gbs, VCO 2-B_Paste.gbp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]
2026-04-02 Added full panel dimensions
    [VCO 2.kicad_pcb]
2026-04-03 Started FP visuals, corrected SPDT SW footprint.
    [VCO 2.kicad_pcb]
2026-04-03 Updated switch footprint to use imported footprint
    [controls.kicad_sch]
2026-04-04 Version confirmed to production
    [VCO 2-B_Cu.gbl, VCO 2-B_Fab.gbr, VCO 2-B_Mask.gbs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]
2026-04-04 Removed unused switch
    [Toggle_SW_Blue_R0.step]
2026-04-13 Fixed switches, added new FPs and symbols.
    [VCO 2-B_Cu.gbl, VCO 2-B_Fab.gbr, VCO 2-B_Mask.gbs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]
2026-04-13 Updates for BOM
    [VCO 2.csv, VCO 2.kicad_sch]
2026-04-13 Consolidated BOM
    [VCO 2 shopping.csv]
2026-04-22 Updates to BOM
    [VCO 2 shopping.csv, VCO 2.kicad_pcb]
2026-06-11 Corrected connections for levels and octave switch
    [VCO 2.kicad_pcb, VCO 2.kicad_sch, controls.kicad_sch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]
2026-06-11 Updated to correct for DRC check and refreshed fab files
    [VCO 2-B_Cu.gbl, VCO 2-B_Fab.gbr, VCO 2-B_Mask.gbs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]
2026-06-12 Tweaked routes
    [VCO 2-B_Cu.gbl, VCO 2-B_Fab.gbr, VCO 2-B_Mask.gbs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]
2026-08-07 Fixed oct selector and updated gnd islands on main
    [VCO 2.kicad_pcb, controls.kicad_sch]
2026-08-07 Updated ignore and cleaned up
    [VCO 2-B_Cu.gbl, VCO 2-B_Fab.gbr, VCO 2-B_Mask.gbs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]
2026-08-14 Updated unflipped connector on control
    [VCO 2.kicad_pcb]
2026-08-14 Reversed power oct. selector and flipped power in
    [VCO 2-B_Cu.gbl, VCO 2-B_Fab.gbr, VCO 2-B_Mask.gbs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]
2026-08-19 Reverted power connection switch and updated schematics.
    [VCO 2.kicad_pcb, VCO 2.kicad_sch]
